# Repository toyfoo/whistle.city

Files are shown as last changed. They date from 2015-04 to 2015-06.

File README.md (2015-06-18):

whistle.city
============

Whistle.city is a social urban game that improves the perception of neighbourhoods. It works with interactive objects called Sparrows, which are adopted by participating citizens and organisations and attached to their building’s windows.
When someone whistles in the vicinity of a Sparrow, it lights up playfully in various colours and animations. The Sparrows are network-connected into the [whistle.city](http://whistle.city) platform on which activity data is visualised. You can follow how your street’s Sparrow is doing. Collectively you can grow your neighbourhood Sparrow, and get it in fantastic shape!

Whistle.city has been played in various forms and names, such as in Ghent (ZWERM, 2013) and is still active in Hasselt (De Mussen van Hasselt).

The Sparrows are Open Source hardware and software, so anyone can build and adapt on the concept (for non-commercial purposes). Citizens, local organisations, coders, school teachers, students, hackers, artists, social workers, researchers, FabLab masters,… can be gathered in workshops to identify locations, explore collaborations and discuss possible integration and adaption of the whistle.city project in your city. 

Hardware
--------
You can find construction details and the descriptions on the required materials in the "Sparrow Assembly Instructions”. If you are interested in buying a kit containing all required hardware for assembly, contact us via http://whistle.city

Software
--------
The Sparrow software is [OpenFrameworks](http://openframeworks.cc) code. We use an [Olimex A20](https://www.olimex.com/Products/OLinuXino/A20/A20-OLinuXino-MICRO/open-source-hardware) running Debian Linux, but should be easily adaptable to [Raspberry Pie II](https://www.raspberrypi.org). If configuring Debian for OpenFrameworks and installing the ofxHwdPlugin addon dependencies confuses you, contact us for a fully functional disk image and/or further instructions at [whistle.city](http://whistle.city)

1. Follow [instructions](https://www.olimex.com/wiki/A20-OLinuXino-MICRO) of installing and configuring the Olimex A20
2. Download [OpenFrameworks for ARMv7](http://openframeworks.cc/download/) and follow the instructions.
3. Copy the "ofxHwdPlugin" addon to your OpenFrameworks addon folder. Currently works on ARM Debian, but we are working on a mac-port. Copy the SparrowsII folder to your OpenFrameworks apps > myApps folder. 
4. You will probably want to enable some scripts to auto-start the Sparrows application on startup.

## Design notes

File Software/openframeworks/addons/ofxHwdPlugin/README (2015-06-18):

The ofxHwdPlugin consists of two components:
- HwdPlugin: places under ofxHwdPlugin/libs, does not depend from oF classes, but depends from some libs shipped with oF (e.g. rtAudio).
- Wrapper for convenient usage with oF: places under ofxHwdPlugin/src.

Building the HwdPlugin for ARM/Linux (e.g. Olimex A20) with Code::Blocks

There is already built plugin for ARM/Linux, and no special actions need to use the plugin from an app. But, if desired, the plugin may be rebuilt. Building the plugin is mandatory for other platform, e.g. Mac.

The HwdPlugin has the following dependencies:
- FFTW;
- RtAudio from oF bundle (RtAudio from oF bundle for one's requires: asound and pulse-simple (these libs are in system)).

There is project file for Code::Blocks. To build: 
1. From Code::Blocks IDE open project file ofxHwdPlugin/libs/HwdLib/HwdLib.cbp.
2. Build. Built files are places under ofxHwdPlugin/libs/HwdLib/lib/linuxarmv7l.

Building the HwdPlugin for Mac with Code::Blocks (not checked)

There is no special Code::Blocks project file for Mac. The one for ARM/Linux must be used and edited. Dependencies are still the same, but there may be some difference in library names (e.g fftw-3 instead fftw), so to fix this issue ofxHwdPlugin/libs/HwdLib/HwdLib.cbp must be edited. Also, output for ARM/Linux is "linuxarmv7l" folder and for Mac there must be some other. Again, ofxHwdPlugin/libs/HwdLib/HwdLib.cbp must be edited to fix this folder name. Then the edited HwdLib.cbp may be used to build for Mac with Code::Blocks.

Building the HwdPlugin for Mac with XCode (not checked)

You must create to project with output target - static library. Then add to the project all plugin source files (all *.h and *.cpp files under ofxHwdPlugin/libs/HwdLib/src, recursively). Then add dependencies: fftw, rtaudio (rtaudio may require additianal dependencies: at least asound and pulse-simple under ARM/Linux). At successful built static lib will created. This lib must be placed under ofxHwdPlugin/libs/HwdLib/lib folder.

Changelog:

v0.0.0: 
Initial version

v0.1.0:
- More convenient usage with oF (Poco::FastMutex is under the wrapper, etc.)

v0.1.1:
- No functional changes. Changes in addon_config.mk to directly specify the addon source files; this breaks recursive directory scanning by oF's make scripts and allows to the plugin source files to be unhidden (previously, these files were packed). The plugin may be compiled immediately from Code::Blocks with ofxHwdPlugin/libs/HwdLib/HwdLib.cbp file. The plugin wrapper (ofxHwdPlugin/src/ofxIntegratedWhistleDetector.h,cpp) is compiled from a user project.
- Removing transient "HwdLib" folder under fxHwdPlugin/libs/HwdLib/src
- Using relative pathes for "Custom Variables" (AKON_INCLUDE and OF_ROOT) in ofxHwdPlugin/libs/HwdLib/HwdLib.cbp. 

v0.2.0:
- Changes in the algorithm (using noise compensation, 1024 samples for STFT, changes in looking range).
- Added whistle sequence detector (ofxWhistleSequenceDetector).

v0.3.0:
- Changed ofxWhistleSequenceDetector::Transition::sequenceId() behaviour.
- Added ofxWhistleSequenceDetector::reset().
- Added ofxWhistleSequenceDetector's final state special behaviour (only state changing on timeout).

v0.4.0:
- Changed ofxWhistleSequenceDetector's final state behaviour: timeout counts from last whistle, not from state enter.

v0.5.0:
- WhistleDetector: added second power threshold to fix whistle end. Averaging over all whistle contour, not last points only.

v0.5.1:
- ofxWhistleSequenceDetector: replaced buggy clock() with ofGetSystemTime().

v0.6.0:
- Changes in the algorithm (Akon::HwdLib::WindowSpikeDetector, Akon::HwdLib::WhistleDetector).
- Added overtone detector (dywapitchtrack) to filter out speech, cat's sounds, vocal sounds. 
- Added weak spikes shadowing after strong ones (on Olimex A20 (may be it is particular mic feature) at end of a whistle there is very weak tail that may detected as a whistle).
- Added signal power threshold (Akon::HwdLib::FramePowerComparator); signal below the threshold is ignored, this prevents false positives from "silence". 
- More exact whistle frequency determination (interpolation).
- Added whistle duration info.

v0.6a(mac).0:
- Added MAC OS X support and Xcode project files (was tested with MAC OS X 10.8.5 Mountain Lion and Xcode 5). Due to using libc++ to have C++11 in the plugin, there is only possible dynamic library of HwdLib to hide libc++ inside.  
- Removed Code::Blocks (ARM/Linux) project files for simplicity.

v0.7.0
- Added MAC OS X support and Xcode project files (was tested with MAC OS X 10.8.5 Mountain Lion and Xcode 5). Due to using libc++ to have C++11 in the plugin, there is only possible dynamic library of HwdLib to hide libc++ inside.  
- Added overtone detector on/off live setting.

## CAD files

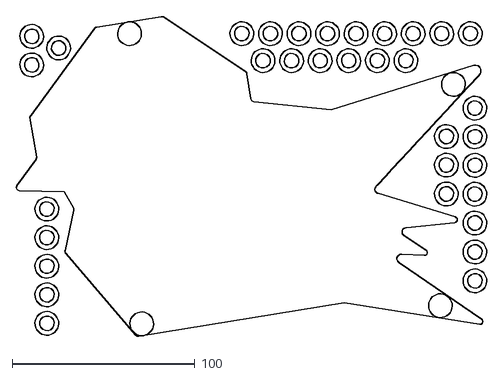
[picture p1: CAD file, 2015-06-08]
Hardware/Sparrow/parts/sparrow_3mm_transparent_plate.dxf
257.9 x 175.2

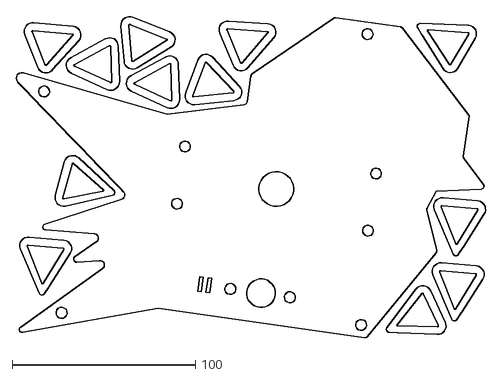
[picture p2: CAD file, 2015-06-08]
Hardware/Sparrow/parts/sparrow_5mm_plate_no-engraving.dxf
256.7 x 175.5

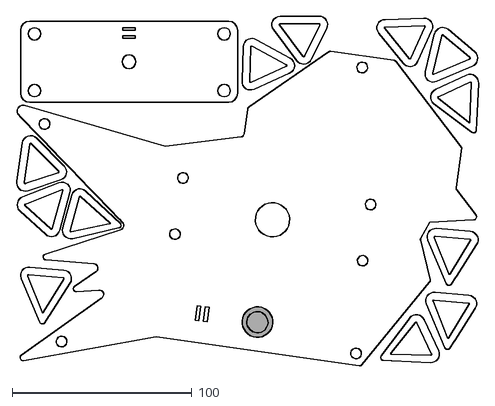
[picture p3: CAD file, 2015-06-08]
Hardware/Sparrow/parts/sparrow_5mm_plate_engraving.dxf
257.0 x 194.4

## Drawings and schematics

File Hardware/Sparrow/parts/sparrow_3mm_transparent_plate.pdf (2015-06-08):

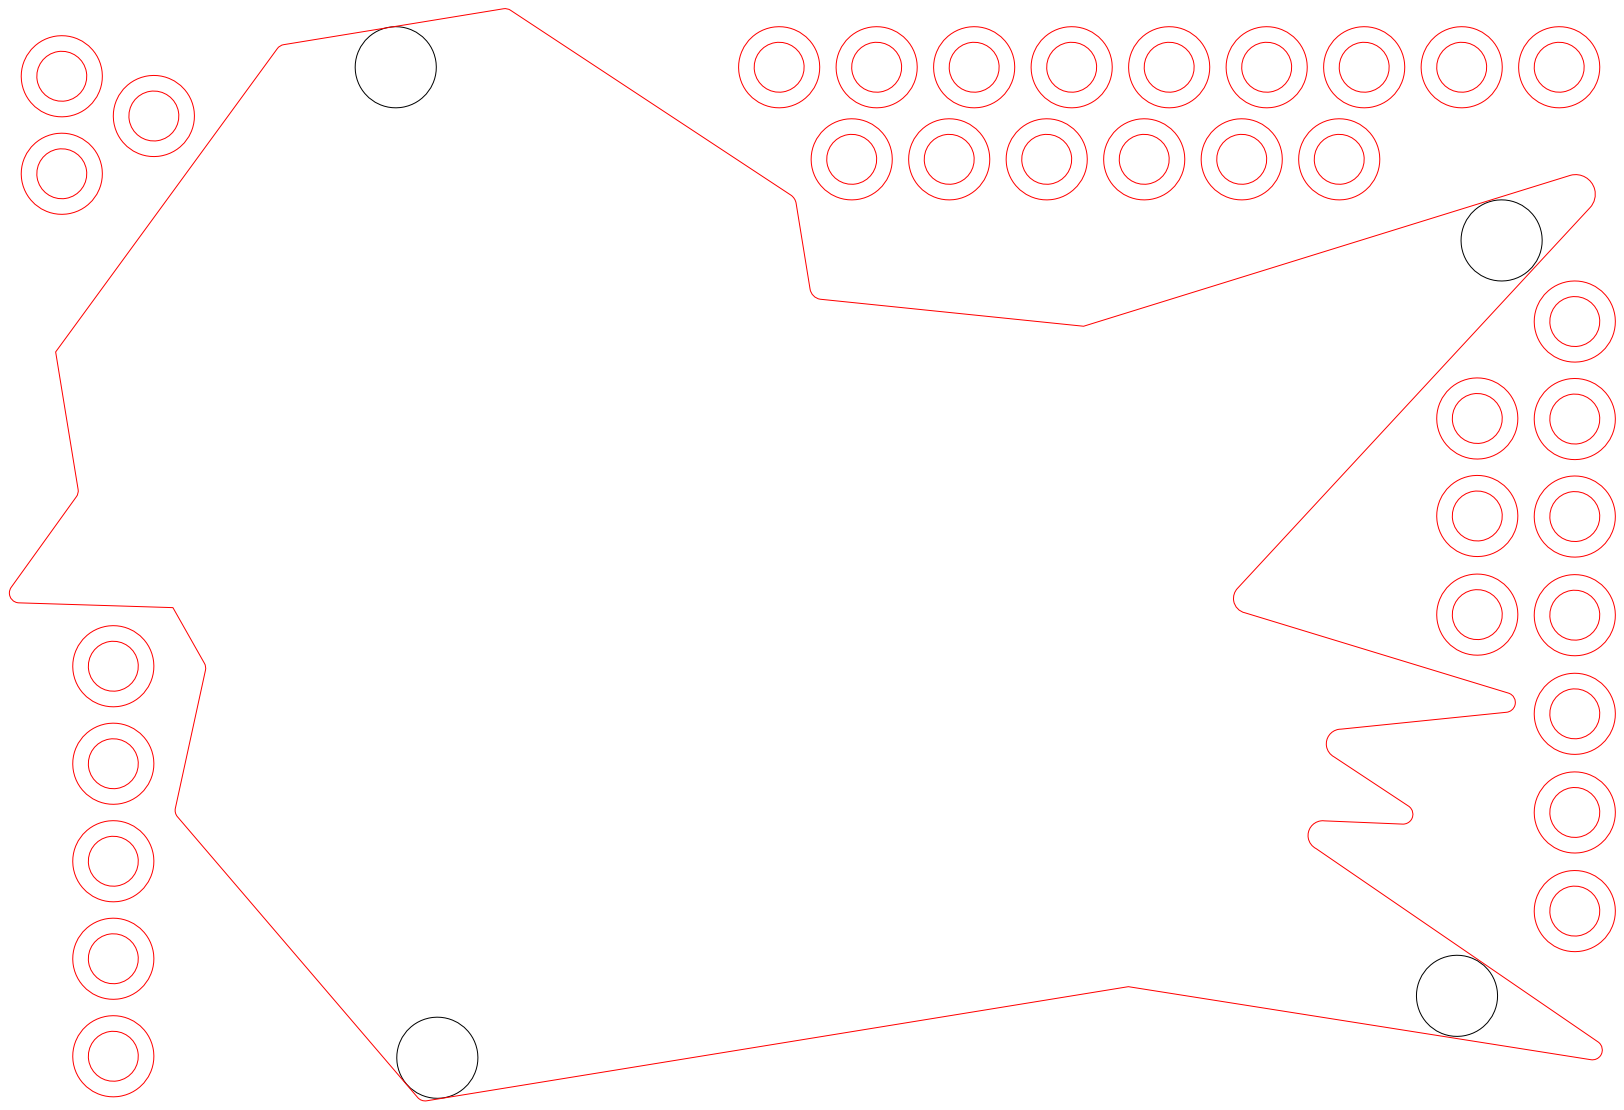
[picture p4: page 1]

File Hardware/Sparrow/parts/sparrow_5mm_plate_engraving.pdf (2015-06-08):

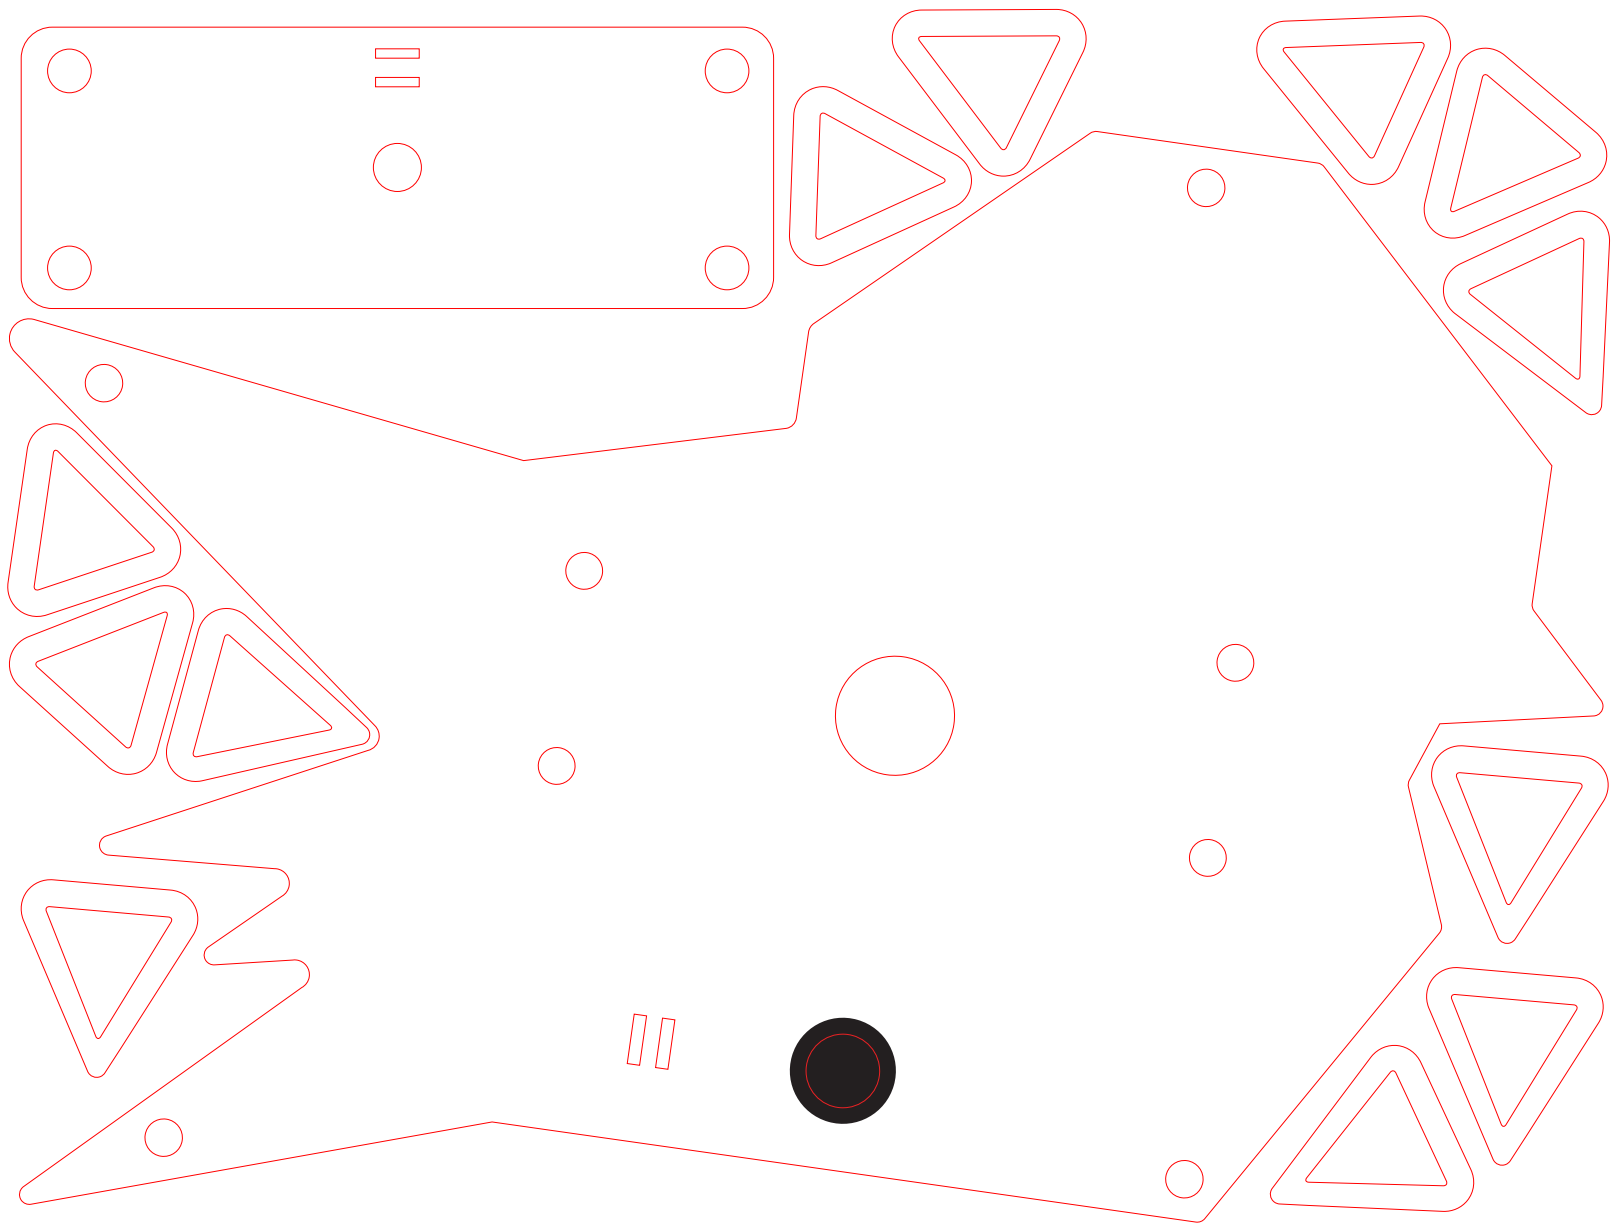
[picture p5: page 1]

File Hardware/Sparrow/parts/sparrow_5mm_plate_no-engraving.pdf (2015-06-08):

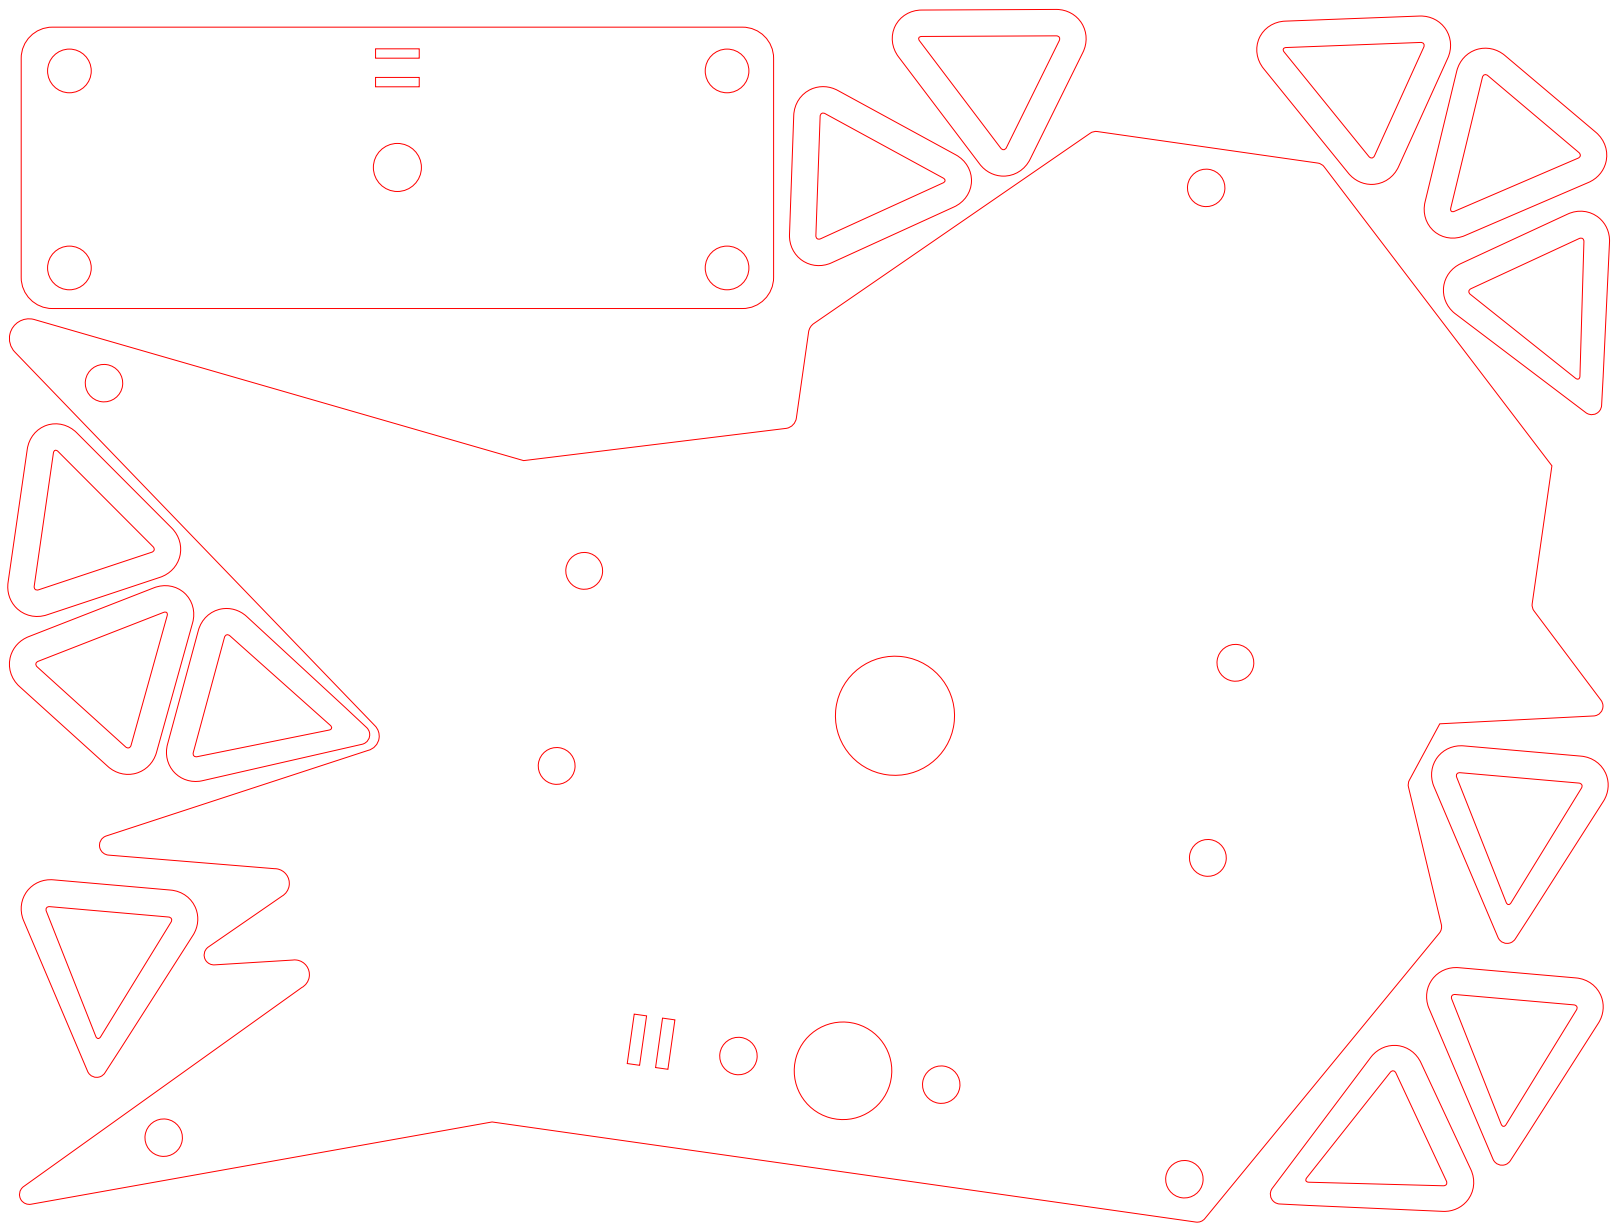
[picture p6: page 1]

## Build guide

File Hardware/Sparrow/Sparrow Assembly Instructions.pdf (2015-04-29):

Version | Designed by | Color Legend | This print is available on http://whistle.city
Parts & Assemblies | Final Sparrow Assembly

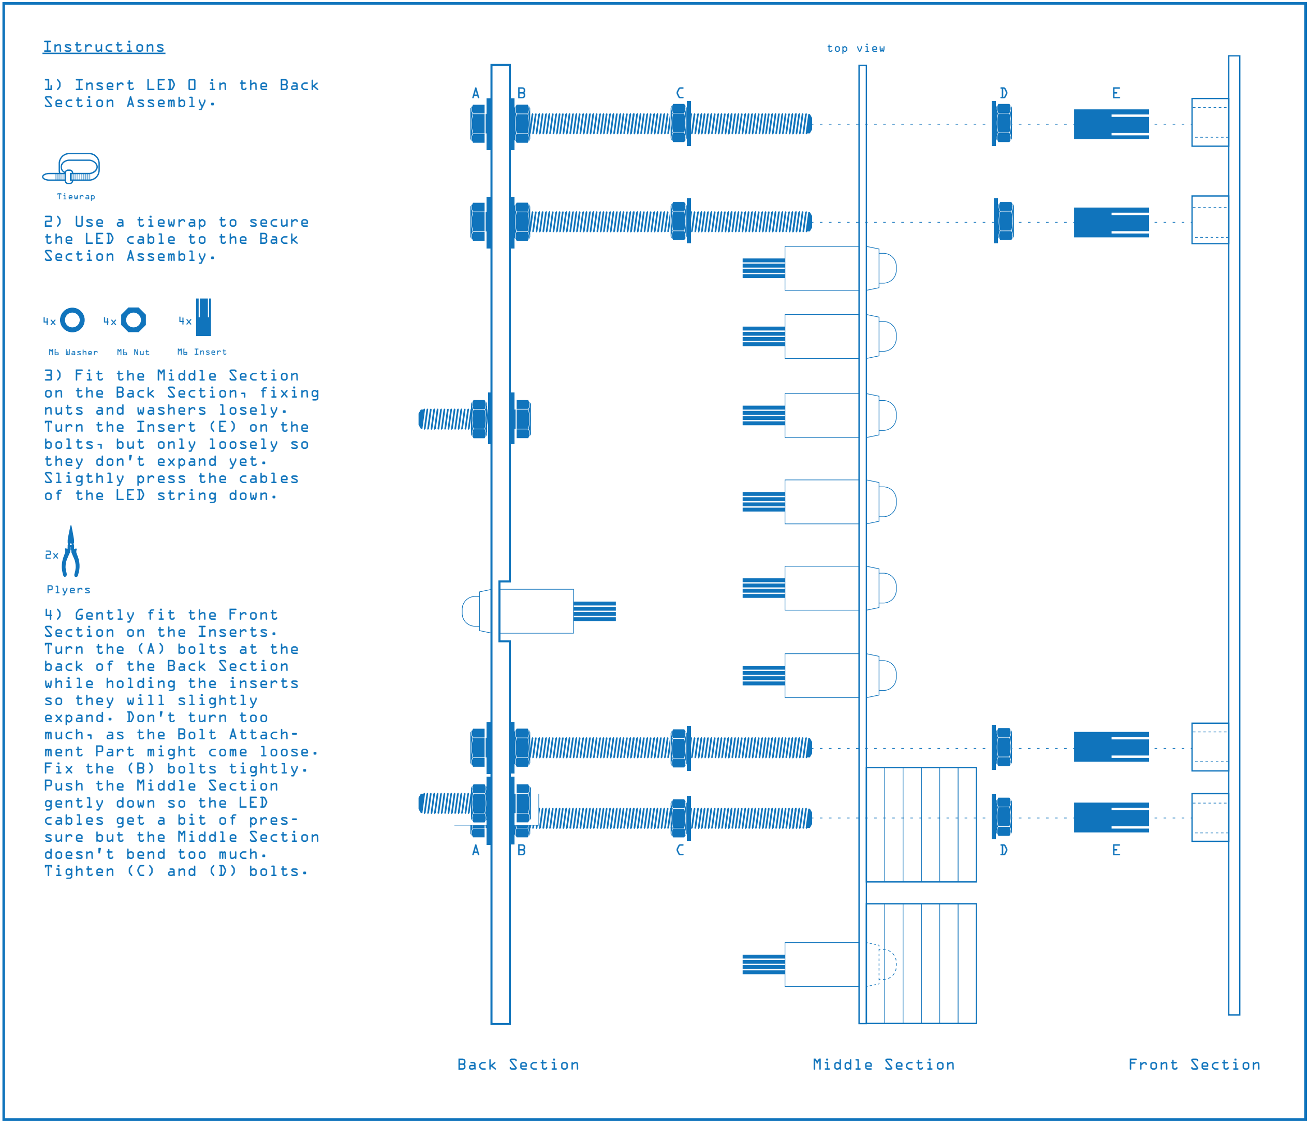
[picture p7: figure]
Back Section; Middle Section; Front Section; Instructions; top view; M6 Insert; Tiewrap; 1) Insert LED 0 in the Back Section Assembly.; 2) Use a tiewrap to secure the LED cable to the Back Section Assembly.; 3) Fit the Middle Section on the Back Section, fixing nuts and washers losely. Turn the Insert (E) on the bolts, but only loosely so they don’t expand yet. Sligthly press the cables of the LED string down.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
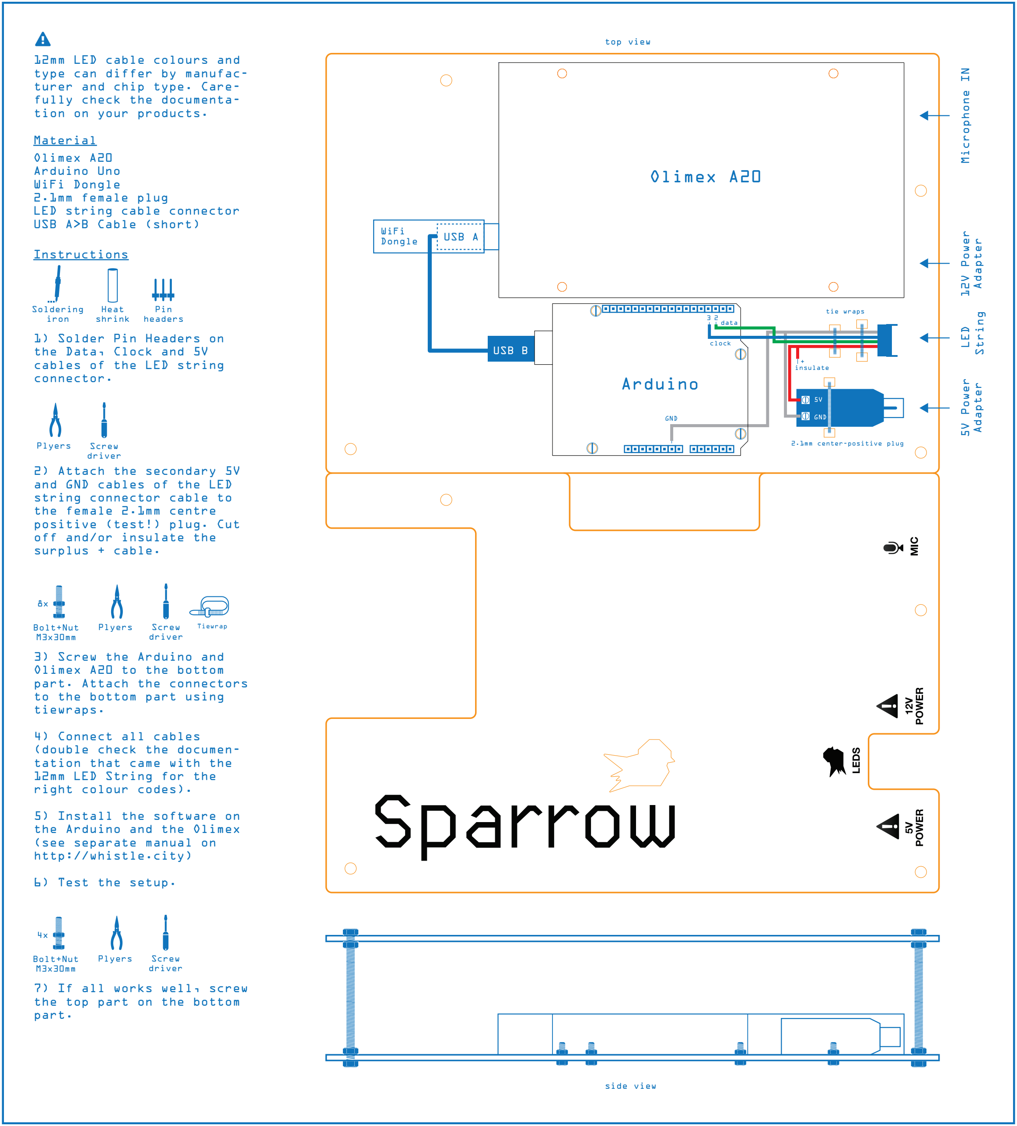
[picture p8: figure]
Olimex A20; Arduino; WiFi Dongle; GND; insulate; 2.1mm center-positive plug; tie wraps; data; clock; Material; Olimex A20 Arduino Uno WiFi Dongle 2.1mm female plug LED string cable connector USB A>B Cable (short); Instructions; side view; top view; Soldering iron; Heat shrink; Pin headers; 1) Solder Pin Headers on the Data, Clock and 5V cables of the LED string connector.; 2) Attach the secondary 5V and GND cables of the LED string connector cable to the female 2.1mm centre positive (test!) plug. Cut off and/or insulate the surplus + cable.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

# In-Situ Installation

# Electronics Module

0.95 | Thomas Laureyssens

Scale

1/1

Orange: | Laser cut
Black: | Laser engraving
Blue: | Instructions

Creative Commons Attribution-NonCommercial-ShareAlike 4.0 International Licence

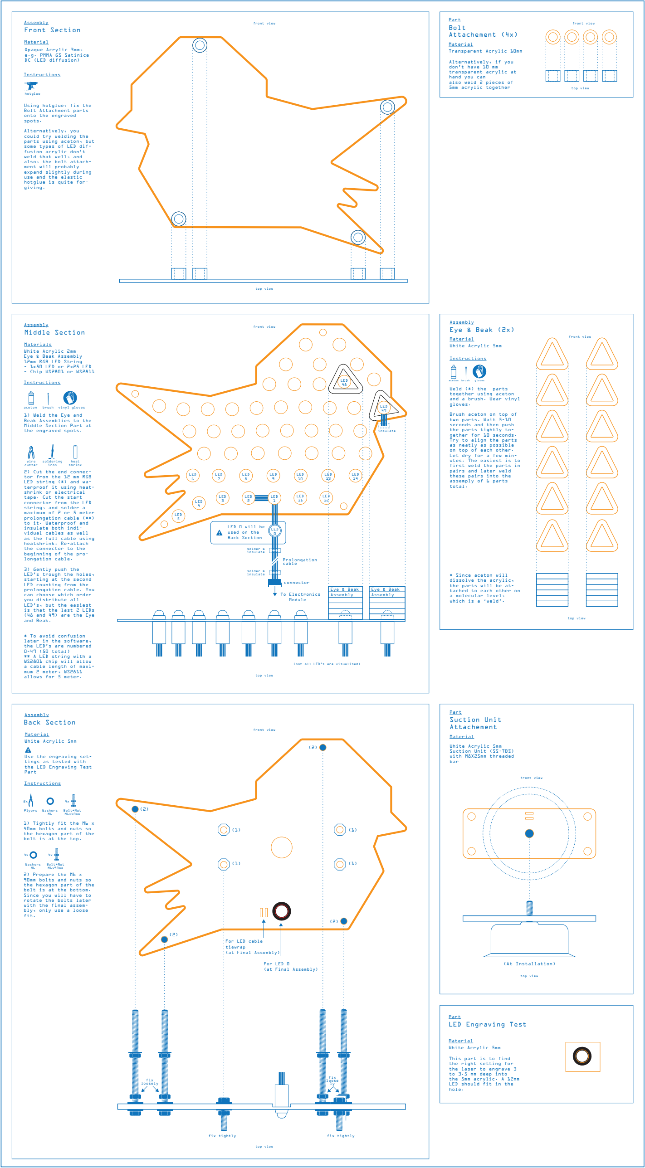
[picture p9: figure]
Eye & Beak (2x); Eye & Beak Assembly; For LED cable tiewrap (at Final Assembly); fix tightly; fix loosely; To Electronics Module; connector; Prolongation cable; solder & insulate; Assembly; Middle Section; Material; Instructions; White Acrylic 5mm; Materials; White Acrylic 2mm Eye & Beak Assembly 12mm RGB LED String - 1x50 LED or 2x25 LED – Chip WS2801 or WS2811; Weld (*) the; parts; together using aceton and a brush. Wear vinyl gloves.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
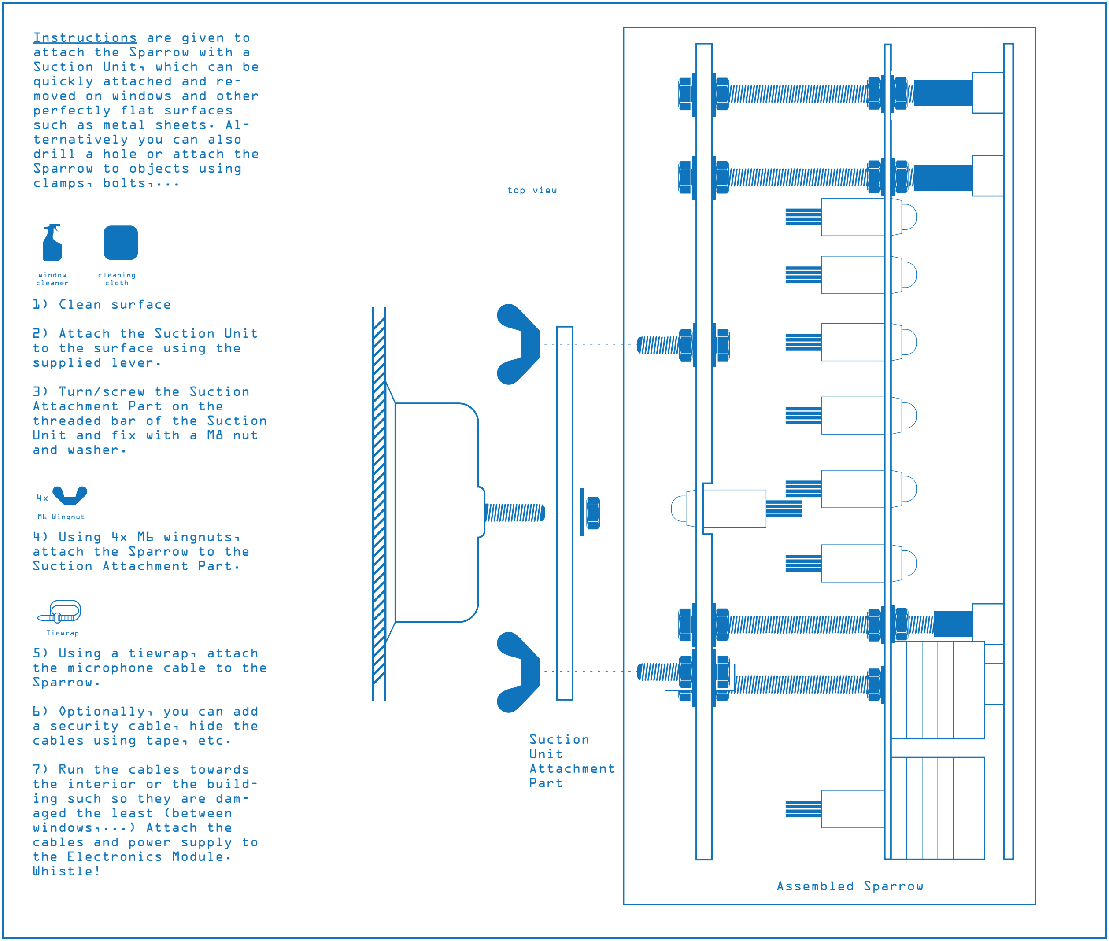
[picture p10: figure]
Assembled Sparrow; Suction Unit Attachment Part; top view; Instructions are given to attach the Sparrow with a Suction Unit, which can be quickly attached and re- moved on windows and other perfectly flat surfaces such as metal sheets. Al- ternatively you can also drill a hole or attach the Sparrow to objects using clamps, bolts,...; window cleaner; cleaning cloth; M6 Wingnut; Tiewrap; 1) Clean surface; 2) Attach the Suction Unit to the surface using the supplied lever.; 3) Turn/screw the Suction Attachment Part on the threaded bar of the Suction Unit and fix with a M8 nut and washer.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

Icons desiner credits (CC) on The Noun Project: Soldering iron created by Semilla Solar, Hot Glue gun by Giulia Malaponti, Plyers by Arthur Shlain, Wing Nut by Jaap Knevel, Bolt and Nut by Mark Hammar, Bottle by Jon Trillana, Spray Bottle by Nithin Viswanathan, Tiewrap by Dan Hetteix, Screwdriver by Pedro Ramalho. http://thenounproject.com

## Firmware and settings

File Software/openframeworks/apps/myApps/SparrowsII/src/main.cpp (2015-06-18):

/// version 0.9
/// by thomas laureyssens t@toyfoo.com

#include "ofMain.h"
#include "ofApp.h"
//#include "ofAppNoWindow.h"

//========================================================================
int main( ){
    
    //ofAppNoWindow window;
    //ofSetupOpenGL(&window,1024,768,OF_WINDOW);
    
    
	//ofSetupOpenGL(1024,768,OF_WINDOW);
    ofSetupOpenGL(550,140,OF_WINDOW);

	// this kicks off the running of my app
	// can be OF_WINDOW or OF_FULLSCREEN
	// pass in width and height too:
	ofRunApp(new ofApp());
}

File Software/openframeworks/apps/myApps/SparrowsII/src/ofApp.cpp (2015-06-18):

/// sparrows
/// version 0.9 - 20 january 2015
/// by thomas laureyssens t@toyfoo.com


#include "ofApp.h"

void ofApp::setup()
{

    // sparrow specific settings
    objectID = "";

    //sparrow design settings
    eyePixel = 48;
    beakPixel = 47;
    maintenancePixel = 49;

    //gamesettings
    gameType = 1;
    timeoutTimeStates = 9000.f;
    timeoutTimeWhistles = 20000.f;
    serverTimeOffHack = 0; // the hours the server is off
    discoChance = 5;  // percentage chance there is discolight (after a minimum of 15 whistles)

    // animation settings
    fadeOutTime = 1000.f;
    fadeInTime = 500.f;
    fadeVariationTime = 30.f;

    maintenanceNoError = ofColor::green;
    maintenanceError = ofColor::red;
    eyeWhistleDetected = ofColor::green;
    eyeWhistleUncertain = ofColor::orange;
    eyeListening = ofColor::grey;
    beakConnectionError = ofColor::red;
    beakPointSent = ofColor::green;
    beakPointEnabled = ofColor::brown;

    status200 = ofColor::green;; // success
    status461 = ofColor::blueViolet;; // no active campaign
    
    
    status400 = ofColor::darkorange; // error
    status400severe = ofColor::red; // connection error - about to set whistles to zero
    status400webserver = ofColor::magenta; // webserver down

    // ofApp settings
    ofSetVerticalSync(true);
    //ofSetLogLevel(OF_LOG_VERBOSE);
    ofSetFrameRate(25);
    ofSetWindowTitle("Sparrows");

    // other settings
    serialSleepMillis = 5; // amount of pause not to choke the serial connection

    //zeroing variables
    serialActivated = false;
    webserverDown = false;
    lastWhistleTime = 0;
    whistlesToSend = 0; //todo: save this to an xml file in case the app restarts
    isLoading = false;
    
    noActiveCampaign = false;
    freshMessage = false;
    returnMessageReceived = 0;
    whistleState = 0;
    whistleIsCertain = false;
    previousWhistleTime = 0;
    
    //firstConnectionTest = false;
    
    hasConnectionError = false;
    hasSevereConnectionError = false;
    connectionDownTime = 0;
    
    timeIsOff = true; //by default, the time can be off so we're sure the whistle function runs until the time is synchronised with the time servers by the system
    lastWhistleFrequency = 0;
    discoLevel = 0;
    discoTried = 0;

    // event registration
    ofxKeyframeAnimRegisterEvents(this);
    ofRegisterURLNotification(this);

    //*
    // GUI
    whistleButton.addListener(this,&ofApp::whistleButtonPressed);
    activateSerialButton.addListener(this,&ofApp::activateSerial);

    // setting gui size 300, 18
    ofxGuiSetDefaultWidth(250);
    ofxGuiSetDefaultHeight(18);

	gui.setup("Sparrow Configuration", "settings.xml", 170, 3);
    //gui.add(HzPerWindow.setup("HzPerWindow", 100, 10, 500)); // a window width in frequency domain within signal energy is integrated; then ratio of windowed energy to entire signal energy is used as a spike value; the window floats across frequency axis. A good whistle has very narrow window ~10 Hz. Whistle on spectrogram looks as line. The line thickness shows frequency band the whistle occupies. Good whistle has very narrow band ~10 Hz , bad - 100s of Hz. In ideal, Spike Window must exactly cover a whistle, but we don't know the whistle in advance. Spike Window lower values - more matching for good whistles, higher values - decreasing certainty of good whistles but allowing bad whistles. Spike Window = 100 Hz is reasonable value from my experimentation.

    //gui.add(powerThresholdPercent.setup("powerThresholdPercent", 80, 1, 100)); // minimal value of spike energy to be considered;
    // Look the output: Whistle detected: frequency 1754.96Hz, certainty (Ewin/Eblock) 0.858128
    // In this case Ewin/Eblock = 0.858128 and this is an averaged ratio of signal energy within Spike Window to energy of entire signal block (FFT frame). Another words, this ratio shows how much energy is contained in the whistle. In noisy environment this value would be lower, in clean - higher. The threshold discards signal with such ratio below.

    //gui.add(msecsPerWhistleDuration.setup("msecsPerWhistleDuration", 500, 50, 1000)); // minimal whistle duration (msecs.) to be considered
    // If we detect a whistle (it may be false whistle) that has less duration, this whistle is discarded.  At a small value ~10s msecs there a lot of false positives from ordinal speech. Values ~100s msecs stop such alarms. A simple way to increase reliability is to set relatively big value, 250 msecs or 500 msecs or even 1000 msecs.

    //gui.add(hzPerFrequencyDeviation.setup("hzPerFrequencyDeviation", 100, 20, 500)); // maximal allowed frequency shift between two consequitive (in time) spikes. Between two FFT frames whistle frequency may change (e.g. increasing or decreasing tone whistling - looks on spectrogram as a line with some angle to horizontal axis). The parameters cuts off too steep lines (discards respective whistles).

    gui.add(debugToggle.setup("Debug", true));
    gui.add(activateSerialButton.setup("Activate Serial"));
    gui.add(debugWhistleCertainty.setup("debugWhistleCertainty", 0.0, 0, 1));
    //gui.add(debugWhistleFrequency.setup("debugWhistleFrequency", 10000, 8000, 20000));
    gui.add(whistleButton.setup("whistle"));




    font.loadFont("DIN.otf", 10);

    
    // drawing pixels on screen for debug purposes
    int xposstart = 3;
    int xpos = xposstart;
    int ypos = 3;
    for(int i = 0; i < pixelAmount; i++){
        pixels.push_back(new Pixel());
        pixels[i] -> ledpos = i; // adding the position in the LED strip
        pixels[i] -> set(xpos,ypos,12,12);
        xpos += 15;
        if(xpos >= xposstart + 150) {
            xpos = xposstart;
            ypos += 15;
        }
        pixels[i] -> setup();
    }
    pixels[beakPixel]->partType = "beak";
    pixels[eyePixel]->partType = "eye";
    pixels[maintenancePixel]->partType = "maintenance";


    // load xml settings
    if (settingsXML.load("sparrowsSettings.xml") ){
        ofLog(OF_LOG_NOTICE, "sparrowsSettings.xml loaded!");
	} else {
        settingsXML.addChild("Sparrows");
        settingsXML.setTo("Sparrows");
        ofLog(OF_LOG_NOTICE, "unable to load sparrowsSettings.xml check data/ folder!");
	}

    if(!settingsXML.exists("//objectId")) {
        settingsXML.addChild("objectId");
    }
    if (settingsXML.getValue("//objectId") == "") {
        settingsXML.setValue("//objectId", "undefined_in_sparrow_code");
    } else {
        objectID = settingsXML.getValue("//objectId");
    }
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

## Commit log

2015-04-29 added Sparrow Assembly instructions
2015-06-08 laser parts
    [sparrow_5mm_plate_engraving.dxf, sparrow_5mm_plate_no-engraving.dxf]
2015-06-08 added transparanten laser plates
    [sparrow_3mm_transparent_plate.dxf]
